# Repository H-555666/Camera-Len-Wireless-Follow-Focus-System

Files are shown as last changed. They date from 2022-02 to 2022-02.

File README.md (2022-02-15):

# Camera-Len-Wireless-Follow-Focus-System
***Many documents are not yet complete, the initial version has been released, please wait🌛***

**[简体中文](https://github.com/ZhongWwwHhh/Camera-Len-Wireless-Follow-Focus-System/blob/main/README_ZH_CN.md)**

## Brief Instructions for Use
If you are an enthusiast and only want to make and use it personally, check this document: [Brief instructions for use](https://github.com/ZhongWwwHhh/Camera-Len-Wireless-Follow-Focus-System/blob/main/Documentation/Quickstart.md)

## Developer
This project always welcomes your guidance and help!!!  
This project was designed exclusively for Raspberry Pi Pico.
If you want to use it on other micropython-capable microcontrollers(such as a more powerful Arduino or pyboard), there's another [code explanation](https://github.com/ZhongWwwHhh/Camera-Len-Wireless-Follow-Focus-System/blob/main/Documentation/Codeinterpretation.md) will make this process easier

## Introduction to Project
The project currently implements a rocker potentiometer (the one on an aeromodelling remote control) to remotely and wirelessly control a stepper motor.  
It only requires two Raspberry Pi Pico, a ULN2003 and its driven stepper motor, and a pair of wireless transceiver modules, aiming to achieve the same functional equipment as an expensive commercial wireless follower.  
***In the future, it will gradually increase to be able to control the version of three motors, and add more powerful functions such as A-B point limit, see [Development Log](https://github.com/ZhongWwwHhh/Camera-Len-Wireless-Follow-Focus-System/blob/main/Documentation/Updatelog.md)***  
Receiver and transmitter use the same modular hardware design (PCB), Transmitter-receiver conversion can be achieved by simply brushing different programs  
All software will use micropython for easy modification and application, and all hardware will be designed with Kicad

## Development and business use
Please note: **All software and hardware in this repository follow GPL3. 0 (GNU General Public License v3.0)**  
You can **get usage modifications**, but everything will continue to follow GPL3. 0 Protocol  
If you make it a commodity, then you **have to** let **anyone** know **its nature and get the source code / source design file**  
See for more information [original GPL3.0 file](https://github.com/ZhongWwwHhh/Camera-Len-Wireless-Follow-Focus-System/blob/main/LICENSE)

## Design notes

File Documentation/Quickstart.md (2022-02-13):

## 硬件准备
**2\*Pico**  
**2\*EBYTE-E28-2G4T12S(SX1280 无线串口模块)**  *我选择了这个模块因为它相对便宜的售价和在使用全向天线时长达3km的控制范围*  
**1\*ULN2003驱动板+28BYJ4步进电机**  *这是一个即将改动的设计，因为我发现它不太适合应用在这种场合中(转速偏慢)*  
**1\*摇杆电位器**  *我使用的是16mm大小，阻值10k，上下自动回中型*  
**1\*0.8模的齿轮**  *需要一个合适的齿数，目前看来35齿左右都较合适*  ***它一定要和电机配合适当***  
**2\*PCB在[这里](https://github.com/ZhongWwwHhh/Camera-Len-Wireless-Follow-Focus-System/tree/main/PCB)**  ***你需要一家PCB制造厂商，我推荐[嘉立创](https://www.jlc.com/)的免费打样***  
**一些线材**  
**焊接工具**

## 组装
在PCB上已经有十分完善的丝印标注，你可以直接将对应模块放置到位并锡焊  
你应该在其中一块板上放置电位器，另一块板连接步进电机驱动板并合理的为它们供电  
**注意：请优先将电位器和电机驱动板焊接在1号接口，因为相对超前的PCB设计，按钮和2、3号电位器/电机的焊盘已经预留，但它们还不能发挥作用**  
**小心：各个模块(尤其是邮票孔)似乎不太适合使用电烙铁直接焊接，恒温热风枪是最好的选择(一定要恒温，否则极易过热损坏)，但我用烤箱的效果十分好**

## 软件刷写
micropython的推荐IDE是[Thonny](https://thonny.org/)  
**Pico的初次使用请参见 [树莓派官网](https://www.raspberrypi.com/)**  
下载最新发布的脚本：[发布页](https://github.com/ZhongWwwHhh/Camera-Len-Wireless-Follow-Focus-System/releases)  
分别将两个文件配置为你想要的参数并刷入对应的设备  

## 完成
！！！！！

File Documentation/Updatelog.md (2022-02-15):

## 1.x
### 1.0
☑️单遥感电位器对远程步进电机的遥控  
☑️速度、方向、对应范围的可调节设计  
☑️初版PCB
### 1.1
❎步进电机控制软件结构简化  
❎长时间控制稳定性(假死问题)  
❎对按钮、多电机/电位器接口预留  
❎更换更适合的步进电机

## 2.x
❎正式开始多电机  
❎按钮的功能(A-B点，调频，预设)

## 3.x
☁️自动对焦？这或许是个梦☁️

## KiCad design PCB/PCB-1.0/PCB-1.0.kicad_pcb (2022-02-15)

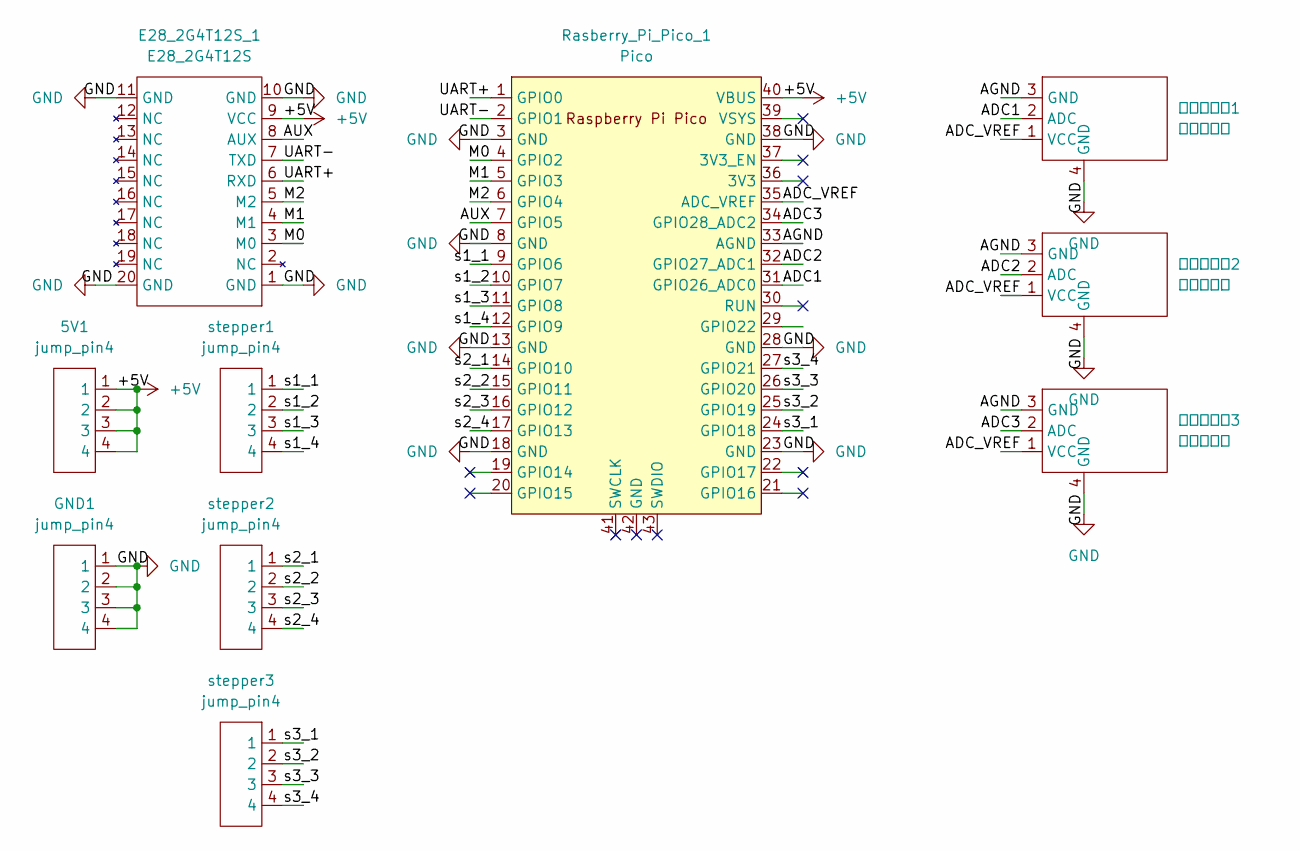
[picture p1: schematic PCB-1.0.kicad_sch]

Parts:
5V1: jump_pin4; SIP-4
E28_2G4T12S_1: E28_2G4T12S
GND1: jump_pin4; SIP-4
Rasberry_Pi_Pico_1: Pico; RPi_Pico_SMD_TH
stepper1, stepper2, stepper3: jump_pin4; SIP-4
摇杆电位器1, 摇杆电位器2, 摇杆电位器3: 摇杆电位器

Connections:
+5V: 5V1.1, 5V1.2, 5V1.3, 5V1.4, E28_2G4T12S_1.9 (VCC), Rasberry_Pi_Pico_1.40 (VBUS)
/ADC1: Rasberry_Pi_Pico_1.31 (GPIO26_ADC0), 摇杆电位器1.2 (ADC)
/ADC2: Rasberry_Pi_Pico_1.32 (GPIO27_ADC1), 摇杆电位器2.2 (ADC)
/ADC3: Rasberry_Pi_Pico_1.34 (GPIO28_ADC2), 摇杆电位器3.2 (ADC)
/ADC_VREF: Rasberry_Pi_Pico_1.35 (ADC_VREF), 摇杆电位器1.1 (VCC), 摇杆电位器2.1 (VCC), 摇杆电位器3.1 (VCC)
/AGND: Rasberry_Pi_Pico_1.33 (AGND), 摇杆电位器1.3 (GND), 摇杆电位器2.3 (GND), 摇杆电位器3.3 (GND)
/AUX: E28_2G4T12S_1.8 (AUX), Rasberry_Pi_Pico_1.7 (GPIO5)
/M0: E28_2G4T12S_1.3 (M0), Rasberry_Pi_Pico_1.4 (GPIO2)
/M1: E28_2G4T12S_1.4 (M1), Rasberry_Pi_Pico_1.5 (GPIO3)
/M2: E28_2G4T12S_1.5 (M2), Rasberry_Pi_Pico_1.6 (GPIO4)
/UART+: E28_2G4T12S_1.6 (RXD), Rasberry_Pi_Pico_1.1 (GPIO0)
/UART-: E28_2G4T12S_1.7 (TXD), Rasberry_Pi_Pico_1.2 (GPIO1)
/s1_1: Rasberry_Pi_Pico_1.9 (GPIO6), stepper1.1
/s1_2: Rasberry_Pi_Pico_1.10 (GPIO7), stepper1.2
/s1_3: Rasberry_Pi_Pico_1.11 (GPIO8), stepper1.3
/s1_4: Rasberry_Pi_Pico_1.12 (GPIO9), stepper1.4
/s2_1: Rasberry_Pi_Pico_1.14 (GPIO10), stepper2.1
/s2_2: Rasberry_Pi_Pico_1.15 (GPIO11), stepper2.2
/s2_3: Rasberry_Pi_Pico_1.16 (GPIO12), stepper2.3
/s2_4: Rasberry_Pi_Pico_1.17 (GPIO13), stepper2.4
/s3_1: Rasberry_Pi_Pico_1.24 (GPIO18), stepper3.1
/s3_2: Rasberry_Pi_Pico_1.25 (GPIO19), stepper3.2
/s3_3: Rasberry_Pi_Pico_1.26 (GPIO20), stepper3.3
/s3_4: Rasberry_Pi_Pico_1.27 (GPIO21), stepper3.4
GND: E28_2G4T12S_1.1 (GND), E28_2G4T12S_1.10 (GND), E28_2G4T12S_1.11 (GND), E28_2G4T12S_1.20 (GND), GND1.1, GND1.2, GND1.3, GND1.4, Rasberry_Pi_Pico_1.3 (GND), Rasberry_Pi_Pico_1.8 (GND), Rasberry_Pi_Pico_1.13 (GND), Rasberry_Pi_Pico_1.18 (GND), Rasberry_Pi_Pico_1.23 (GND), Rasberry_Pi_Pico_1.28 (GND), Rasberry_Pi_Pico_1.38 (GND), 摇杆电位器1.4 (GND), 摇杆电位器2.4 (GND), 摇杆电位器3.4 (GND)

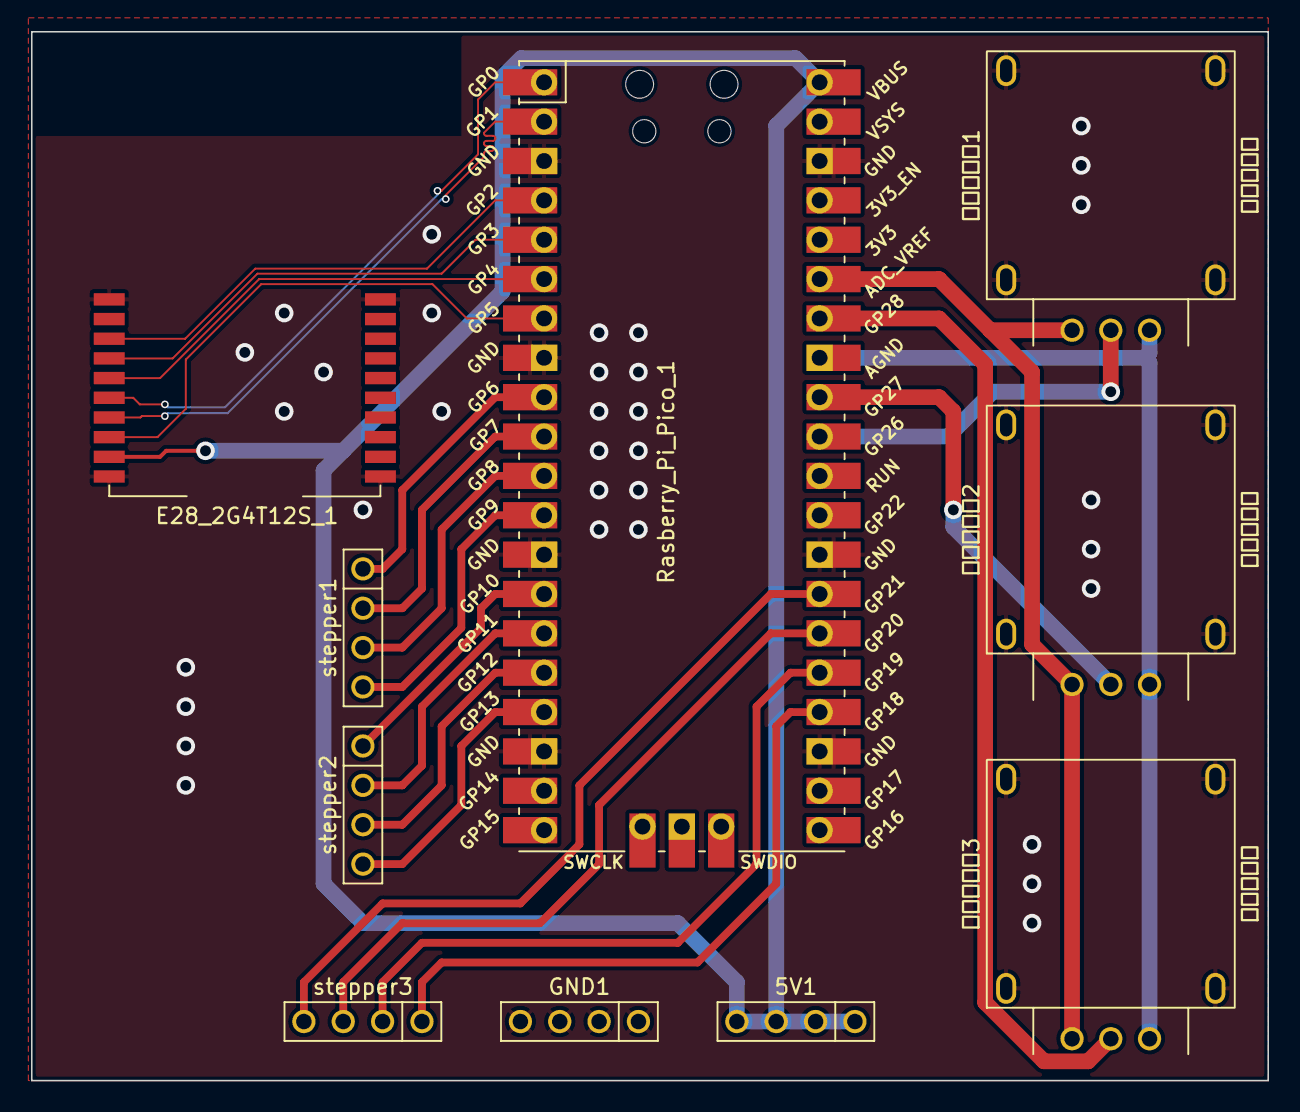
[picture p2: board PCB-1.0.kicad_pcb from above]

Board: 2 copper layers, 79.8 x 67.7 mm, 10 parts (0 on the bottom side), 25 nets.

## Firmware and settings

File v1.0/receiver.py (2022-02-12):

from machine import Pin, UART
import time, _thread

# set GPIO for stepper
s1_1 = Pin(6,Pin.OUT)
s1_2 = Pin(7,Pin.OUT)
s1_3 = Pin(8,Pin.OUT)
s1_4 = Pin(9,Pin.OUT)

# set GPIO for led
led = Pin(25,Pin.OUT)
led.high() # if led light, it is not in working

# set GPIO for E28
uart = UART(0, 9600, bits=8, tx=Pin(0), rx=Pin(1), parity=None, stop=1)
m0 = Pin(2,Pin.OUT)
m1 = Pin(3,Pin.OUT)
m2 = Pin(4,Pin.OUT)
aux = Pin(5,Pin.IN,Pin.PULL_UP)

# wait starting of E28
def E28_start():
    m0.value(0)
    m1.value(0)
    m2.value(1)
    while aux.value() == 0:
        time.sleep_ms(300)
    led.low() # it is  able to work

# led flashing
def led_flash(c, t):
    for x in range(c):
        led.high()
        time.sleep_ms(t)
        led.low()
        time.sleep_ms(t)

# config E28
E28_start()
m0.value(1)
m1.value(1)
m2.value(1)
led.high() # it means that E28 is just configing
time.sleep_ms(500)
uart.write(b"\xc0\x57\x57\x13\x5d\x04") # set the original config to E28
time.sleep_ms(500)
uart.read() # clean the message from uart
E28_start() # now it can work

# control of stepper
def step():
    while True:
        d=direction
        dd=delay
        if d == 0:
            s1_1(0)
            s1_2(0)
            s1_3(0)
            s1_4(0)
            time.sleep_ms(100)
        elif d == 1:
        
            s1_1(0)
            s1_2(0)
            s1_3(0)
            s1_4(1)
            time.sleep_ms(dd)
            
            s1_1(0)
            s1_2(0)
            s1_3(1)
            s1_4(1)
            time.sleep_ms(dd)
            
            s1_1(0)
            s1_2(0)
            s1_3(1)
            s1_4(0)
            time.sleep_ms(dd)
            
            s1_1(0)
            s1_2(1)
            s1_3(1)
            s1_4(0)
            time.sleep_ms(dd)
            
            s1_1(0)
            s1_2(1)
            s1_3(0)
            s1_4(0)
            time.sleep_ms(dd)
            
            s1_1(1)
            s1_2(1)
            s1_3(0)
            s1_4(0)
            time.sleep_ms(dd)
            
            s1_1(1)
            s1_2(0)
            s1_3(0)
            s1_4(0)
            time.sleep_ms(dd)
            
            s1_1(1)
            s1_2(0)
            s1_3(0)
            s1_4(1)
            time.sleep_ms(dd)
        else:
            s1_1(1)
            s1_2(0)
            s1_3(0)
            s1_4(1)
            time.sleep_ms(dd)
            
            s1_1(1)
            s1_2(0)
            s1_3(0)
            s1_4(0)
            time.sleep_ms(dd)
            
            s1_1(1)
            s1_2(1)
            s1_3(0)
            s1_4(0)
            time.sleep_ms(dd)
            
            s1_1(0)
            s1_2(1)
            s1_3(0)
            s1_4(0)
            time.sleep_ms(dd)
            
            s1_1(0)
            s1_2(1)
            s1_3(1)
            s1_4(0)
            time.sleep_ms(dd)
            
            s1_1(0)
            s1_2(0)
            s1_3(1)
            s1_4(0)
            time.sleep_ms(dd)
            
            s1_1(0)
            s1_2(0)
            s1_3(1)
            s1_4(1)
            time.sleep_ms(dd)
            
            s1_1(0)
            s1_2(0)
            s1_3(0)
            s1_4(1)
            time.sleep_ms(dd)

# set an original number for delay and direction
delay = 0
direction = 0

# start the control of stepper
_thread.start_new_thread(step,())

# this is a test
#uart.write('(5,1)')

while True:
    if uart.any()>=1:
        time.sleep_ms(30)
        receive = str(uart.read())
        e = receive.rfind(")")
        s = receive.rfind(",", 0, e)
        direction = int(receive[(s+1):e])
        e = receive.rfind("(", 0, s)
        delay = int(receive[(e+1):s])
    else:
        time.sleep_ms(30)
